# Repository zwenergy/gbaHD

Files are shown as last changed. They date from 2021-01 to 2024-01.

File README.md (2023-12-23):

# gbaHD
An open-source GBA consolizer.

To create a stable video signal without buffering whole frames, but rather
go line-by-line, the quartz crystal of the GBA is removed. Instead, 
the FPGA generates the clock signal for the GBA.

## Note
The latest bitstream (v1.4A) only works in conjunction with a Mancloud
shield. I will update the Arduino FW in the upcoming days, so the latest 
bitstream can be used with all gbaHD.

## Wiring
You need some basic soldering skills to wire all signals of the GBA to the
FPGA board and the controller to the Arduino. All responsibility is on
you. **I do not take any responsibility for any potential damages.** The 
following wiring works well for me. **Yet again, all risk is up to you.
If you want a more out-of-the-box experience, I strongly suggest you to
do not tinker around with your devices.** This is a simply hobby project of 
mine without a lot of testing.

In general, the test points of the GBA motherboard are not made for a
lot of soldering, so try to keep your soldering quick.

### SEA pins
The following figure shows an overview of the pins used for signals on
the Spartan Edge Accelerator board and the pin names used.

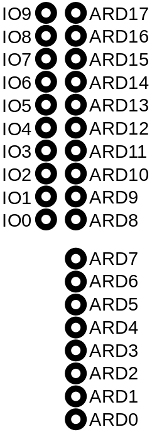
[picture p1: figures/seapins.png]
SEA pins


### Video signals
The following figure shows the test points for the display signals on
the GBA motherboard. I only used a 32 pin model so far, but the 40 pin
should have a similar layout. The test points can be found on the
frontside of the GBA motherboard close to the top.

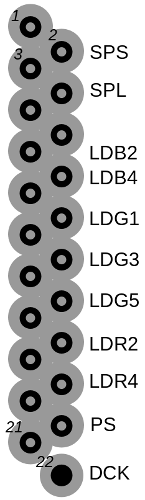
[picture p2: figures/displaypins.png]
SEA pins Display pins


The connections between the GBA display signals and the FPGA board are 
as follows (check the previous figures for the pin names). The "GBA Testpoint" 
column notes the testpoint to be connected to the corresponding FPGA
pin. The next columns (GBA LCD XX-pin) give additional information where
this signal is placed on the display ribbon cable.

| **FPGA Pin** | **GBA Testpoint** | GBA LCD 40-pin | GBA LCD 32-Pin | GBA SP 34-Pin |
|-|-|-|-|-|
| IO0 | 2 | 26 | 25 | 25 |
| IO1 | 5 | 23 | 22 | 22 |
| ARD5 | 6 | 22 | 21 | 21 |
| IO2 | 7 | 21 | 20 | 20 |
| ARD6 | 8 | 20 | 19 | 19 |
| IO3 | 9 | 19 | 18 | 18 |
| ARD7 | 10 | 17 | 16 | 16 |
| IO4 | 11 | 16 | 15 | 15 |
| ARD8 | 12 | 15 | 14 | 14 |
| IO5 | 13 | 14 | 13 | 13 |
| ARD9 | 14 | 13 | 12 | 12 |
| IO6 | 15 | 12 | 11 | 11 |
| ARD10 | 16 | 11 | 10 | 10 |
| IO7 | 17 | 10 | 9 | 9 |
| ARD11 | 18 | 9 | 8 | 8 |
| ARD13 | 19 | 8 | 7 | 7 |
| IO9 | 22 | 3 | 2 | 2 |

### Audio signals
The GBA generates a stereo 8 bit audio signals as a PWM which is then
amplified. We pick up both PWM signals using the following two
connections (the test point names can be found on the silkscreen of the
GBA motherboard).

| GBA Test Point  | FPGA Pin |
|---|---|
| S01 | ARD2 |
| S02 | ARD3 |

### Clock signal
The clock crystal has to be removed and a pad of the former crystal is 
connected to an FPGA pin. The following figure shows which pad has to be 
connected (the highlighted one) to the FPGA pin.

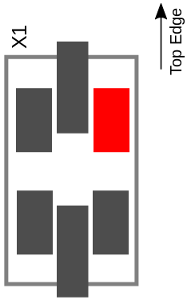
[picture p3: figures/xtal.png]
XTAL pin


| GBA | FPGA Pin |
|-----|---|
| XTAL pad  | IO8 |

### Controller signals
A cheap Arduino (e.g., a small Nano) handles the controller input (the 
FPGA board is not used here, as we would run out of pins here). The
following figure shows the pinout of a SNES controller plug.

SNES pinput SNES pinout

The SNES controller port is connected to the Arduino pins as follows:

| SNES controller | Arduino Pin |
|---|---|
| 5V | 5V |
| Clk | A1 |
| Latch | A0 |
| Data | A2 |
| Gnd | Gnd |

The following table shows the connections between the GBA motherboard
and Arduino pins for simulating the button presses.

|  GBA Test Point  | Arduino Pin |
|---|---|
| TP6 | D2 |
| TP7 | D3 |
| TP5 | D4 |
| TP4 | D5 |
| TP0 | D6 |
| TP1 | D7 |
| TP9 | D8 |
| TP8 | D9 |
| TP3 | D10 |
| TP2 | D11 |

### Arduino-FPGA connection
To activate or change the pixel grid, a connection between the Arduino
and the FPGA board is needed.

|  FPGA Pin  | Arduino Pin |
|---|---|
| ARD4 | A3 |

### Power connections
The GBA and Arduino can be powered via pins of the FPGA board. For the
GBA, the battery holders on the motherboard can be desoldered, as they are
not required anymore. Then connect the "B+" pad of the GBA motherboard to
the "3V3" pin of the SEA board and the GBA's "B-" pad to a GND pin of the
SEA board. Keep the power switch of the GBA on the ON position
(preferably fix it in this position, as the switch is quite smooth-running).

The Arduino requires 5V instead of 3.3V. For this, put the jumper 
"PWR_MODE" to the "ON" position. Then connect the 5V pin of the SEA
board's Arduino ICSP pins to the 5V pin of the Arduino.

## Custom Borders
Custom borders are currently in a kind of experimental state. Border images 
have to be in the dimensions of 320x180 pixels (going with the same resolution
of the Game Boy). Only the border is taken into account, the display area 
(middle 240x160) is ignored (see template.bmp). To generate a custom border, 
execute

`makeBorder.py <IMAGEFILE> (<CUTBITS>)`

The first parameter is the image file for the border, the second is an 
optional parameter for reducing the image color depth. After executing 
the script a new .vhdl should have been created. Replace the original 
`borderGen.vhdl` with this one and run the synthesis.

If the synthesis fails, the border is too complex. Try to simplify the 
border image or use the color depth reduction of the makeBorder.py script. 
The optional parameter sets the number of bits to reduce in color space. 
E.g., setting CUTBITS to 2 will reduce the color depth per color from 
8 bits to 6 bits.

## OSD, Smoothing and Pixel Grid
A 2x smoothing and 4x smoothing can be activated. These are slightly adapted
versions of the Scale2x algorithm. Note: Smoothing is currently disabled 
for 1080p resolution.

The pixel grid feature is currently also in an experimental state. Two
different pixel grids can be applied, a "bright" pixel grid (AGS feeling) 
or a "dark" pixel grid (AGB feeling).

To enter the OSD, press L+R+Select+Right. Smoothing and pixel grids can be activated there.

For the OSD, the connection between the 
FPGA board and the Arduino board (see previous sections) needs to be wired.

## FPGA Firmware
You can find the latest bitstream under the folder *bitstream*.

## TODOs

*README TODO:*
- Describe the overall project.
- Describe the different modules.
- Describe pinouts.
- Describe GBA video timing.

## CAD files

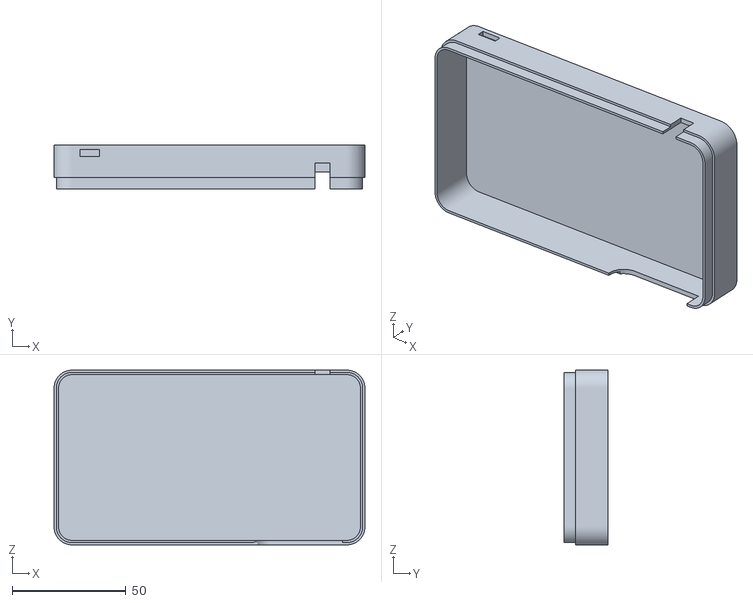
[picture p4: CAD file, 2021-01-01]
case/gbacasebottom.stl
137.0 x 19.3 x 77.0

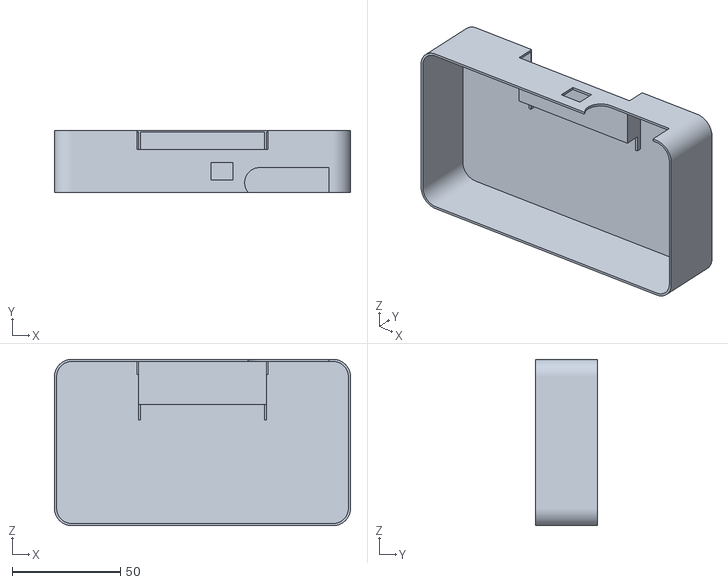
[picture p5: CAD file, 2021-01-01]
case/gbacase.stl
137.0 x 28.6 x 77.0

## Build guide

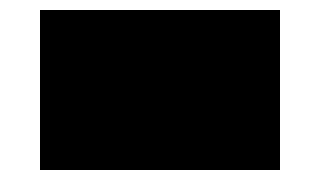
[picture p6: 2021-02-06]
scripts/makeBorder/template.bmp

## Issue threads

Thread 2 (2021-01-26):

Latest build reports 695p signal on some devices

codemasterv, 2021-01-26:
Some devices like my Sony TV, Samsung TV and Elgato HD 60 Pro report a 695p signal and refuse to display.

Other devices such as my Toshiba TV and  report the signal as 720p and works fine

On the previous build it worked on everything but the Samsung

Edit: Fixed in 01/27 update.

zwenergy, 2021-01-26:
I tried to fix it in the current commit. Is it working for you again?

codemasterv, 2021-01-27:
yep just popped in to makrk as resolved. Thanks for the update!

Closed 2021-01-27.

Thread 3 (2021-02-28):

Request / question

PrimoAngelo, 2021-02-28:
Great job! Do you think it is possible to add the pinout for the gamecube controller and the corresponding code for the arduino nano? For those like me who don't have Snes controllers and only have gamecube controllers and GC extension cables to sacrifice. Thanks so much for the work!

Liriel-666, 2021-05-08:
To what I knew use the gc only 1 data line and not 3 (data, clock, latch) .
He works not like a nes or snes pad.
That would need a full other firmware in the arduino.

And to be true gc gamepad are not really good for gba games

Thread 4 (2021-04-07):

The first column of pixels is too wide.

ChristopherHale, 2021-04-07:
The first column of pixels appears to be drawn 1.5 to 2 times the normal width of a pixel and the last column of pixels appears to be partially cut off or thinner. I've attached a photo from the Advance Wars editor screen, notice the left edge of the mountains when they're against the edge of the screen compared to when they're away from the edge of the screen.

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

ChristopherHale, 2021-04-26:
I’m looking into another issue right now but I noticed this extra wide column is misaligning the pixels to the pixel grid effect.

ChristopherHale, 2021-04-26:
![Uploading image.jpg…]()

ChristopherHale, 2021-04-27:
After counting the pixels the first pixel of each line is 9 pixels wide instead of the 6 pixels thereafter. The last pixel in the row is now 3 pixels wide and the pixel grid effect is chopping the pixels down the middle instead of being drawn between the pixels.

ChristopherHale, 2021-05-08:
Here are some more examples with the pixel grid turned on and I'm using a different display. The pixel grid does appear to be positioned correctly with the pixels being shifted partially to the right underneath it. Take note of the lettering and the orange pixels on the mountains. I tried looking through the FPGA code but I didn't see anything that jumps out at me but I'm guessing
 it happens sometime before the pixel grid effect is applied.

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

bkoropoff, 2022-01-30:
@zwenergy this bug should be fixed by #11

ChristopherHale, 2022-01-30:
Awesome! Thanks!

Closed 2022-01-31.

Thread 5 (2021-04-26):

Infrequent Restarts When Using 8bitdo Receiver

ChristopherHale, 2021-04-26:
When using the 8bitdo 2.4G SNES Receiver I’m experiencing infrequent restarts of the GBA and FPGA board. All the LEDs turn off and on again.

This seems to occur after leaving the console running and I’ve witnessed it happening after the first input into the wireless controller. There will then be several restarts in a row.

I haven’t seen this issue with a stock SNES or SFC controller. I’m going to see if I have a similar issue with my Bluetooth controller/receiver combo.

ChristopherHale, 2021-04-26:
I can confirm that the 8bitdo Bluetooth receiver is also causing tiny gbaHD to power cycle and restart. It happens without any interaction with the controller but does take about 5 minutes to occur.

bkoropoff, 2022-01-29:
@ChristopherHale the extra current drawn by a wireless receiver might be exceeding what your power supply can provide.  You could try putting a bypass capacitor across 5v and GND on the SNES controller connector, which will help if the excess current draw is a short transient.

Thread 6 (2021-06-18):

HDMI input recognized as TV input, but black screen

RianBeck, 2021-06-18:
The latest build as available on the google drive of Mogi_codemasterv works on my external computer monitor, however, I get a black screen in my panasonic viera tv (2014 model). I have tried older builds as well, but those don't even get recognized by the tv at all. On the latest build the tv does recognize the aspect ratio (16:9).

Would be very much appreciated if this could be fixed, as I would love to play on my tv, thanks!

Bertuga, 2021-06-24:
This is an issue with the TV. The gbaHD frequency is the same as the GBA which is not 60fps (it is something close to 59.72), a lot of TVs won't accept an irregular frame rate as this one. I'm also an viera owner (older model than yours) and it doesn't work as well, but it is the price to have it working as close as possible as the original hardware.

The GBA consolizer actually works at a 60fps, but the collateral effect of this is that everything runs slightly faster. Maybe it would be possible to implement this "60fps" mode to the gbaHD project, since the consolizer runs in an older fpga thant the gbaHD, to work as a compatibility mode for all TVs (the gba consolizer has two separate firmwares, to run at the original fps or the 60fps). I'm leaving this just as an suggestion, the project is amazing and I couldn't possibly ask for more.

RianBeck, 2021-06-24:
Thanks a lot for the explanation! Makes a lot more sense now. Indeed a 60Hz option would definitely be a nice to have, but as you say, amazing project, and I love it either way!

RianBeck, 2021-10-17:
The latest update has made the gbaHD compatible with my tv, thanks a lot for the great work!

Closed 2021-10-17.

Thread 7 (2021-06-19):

Incorrect vertical alignment

kyokohunter, 2021-06-19:
In my build the GBA video isn't vertically centered correctly. Resetting the ESP32 on the Spartan board changes the vertical alignment to a random position.

I thought this may be a quirk of my setup, as I'm building this around a GameBoy Player. The CPU is held in reset by the Arduino until ready (e.g waiting untile controller connected). I've wired the CPU directly and ruled that out as a cause, as exactly the same issue happens. I also checked my SPS (VSync) wiring with a multimeter and logic analyser and all seems fine there.

I only have one TV to test this on (Philips) and have tried the different HDMI inputs, as well as a couple of different HDMI cables.

I'm using the bitstream from this project as of 2nd June.

kyokohunter, 2021-06-26:
After investigating further it seems most of the time the picture is clipped off the top edge of the screen by about 160 lines.

I've decided to try learning FPGA development to help with this project but please bear with me whilst I learn the ropes (my background is front-end web dev and SQL!).

Increasing gbavideoystart in imageGen.vhd moves the GBA output but it ends up being clipped at the bottom, with the last 160 lines on the screen being blank.

I experimented with changing the countY position that a new frame in causes a jump to (changed to ystart); this causes jitter and lines repeating after the GBA video area.

I also experimented with changing vsync to occur after the active video area instead of before; this didn't make a change but it also didn't break the code.

Finally I experimented with a larger value for vbackporch; however I forgot to change maxVer before finishing work for the moment so I can't say if this would work or not! I'll report back when I can.

kyokohunter, 2021-06-27:
Changing the vfrontporch and vsync constants in imageGen.vhd hasn't made a difference either. I should also say that the TV is reporting 1280x720 at 60Hz correctly for the input and not some other resolution.

kyokohunter, 2021-07-01:
I've tried a different HDMI example and I also get the same problem (doesn't vsync) with that code, so there may be an issue with my SEA board or cables rather than the gbaHD code. I'll close this issue and try another board and cable that I've got on on order.

Closed 2021-07-01.

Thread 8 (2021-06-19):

No sound

kyokohunter, 2021-06-19:
I'm not getting any audio output via my TV. Whilst I'm planning to add a Bluetooth transmitter instead, I've spotted other people mentioning this on Reddit so I thought I would post the issue here.

As with the other issue I raised I only have one TV to test this on (Philips) and have tried the different HDMI inputs, as well as a couple of different HDMI cables and I'm using the bitstream from this project as of 2nd June.

It might be of interest this topic on the MiSTer FPGA forum about audio output issues with the GBA core:
https://misterfpga.org/viewtopic.php?f=20&t=55

neophoriac, 2021-06-19:
The audio issue, to my knowledge, is due to the fact that gbaHD outputs to DVI which originally doesn't carry audio. This means that even if the gbaHD outputs audio some TVs won't recognize it anyway as they don't expect audio. I have the same issue with my LG CX but if I connect it to an Asus monitor I can actually hear audio.

I would urge you to try the gbaHD to a different monitor(s) and see if the issue persist.

bkoropoff, 2022-02-13:
@zwenergy this might be fixed as of 1.3G

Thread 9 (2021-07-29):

Color Issues? (Also odd game issues)

TheIcedTeaAddict, 2021-07-29:
Hello, I must say that I've absolutely loved playing my Gameboy games on the TV with an SNES controller.
But I've ran into two issues so far, one that has been consistent for some reason despite trying wiring everything again. The other is one that I just recently found. So I hope to get some help trying to fix these issues.

The first issue is fairly major, as it is a very strange color issue, which will be included in these photos.
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
I have no idea why this issue has been consistent, but I've even searched up the service manual for the 40 pin motherboard that I have and found nothing that could be causing this. Which is unfortunate since I really wanted to fix this issue myself without making this into a topic.
The first time I tried to build this project, the same thing happened, but I was using the test pads. So I tried again and ended up burning off the gba pads, once I did this I ordered a ribbon cable PCB so I could use the LCD cable slot. which worked, but gave me the same results. So I took all the wires off the FPGA board and resoldered better/thicker wires onto them and another ribbon cable PCB, still same result, so right now I feel like I'm at a dead end. I hope to get some possible solutions that could help fix this issue.

Now here is another issue I ended up finding, I have reproduction copies of Metroid Fusion, Harvest Moon and a few other games, but only the first two have issues. Both Metroid Fusion and Harvest Moon hang after getting past the Game Boy Advance logo. No sound and only a blue tinted screen. (It would be a white screen, but the color issue above.) I assume because these two have the same board and both are missing a 1n4148 Diode, but I find it odd since these two work just fine on my SP. Either way, I don't care much if this issue fixed on the end of GBAHD as I could probably fix it by soldering a diode to the pads, I just found this issue interesting and strange to think about. lol. (If you are interested in looking into this for some reason, the boards are BX2006_TSOPGA_6108.)

TheIcedTeaAddict, 2021-07-30:
Just going to add that this a AGB-CPU-04 board with a CPU AGB A. Going to mention that in case that's important for this.

ManCloud, 2021-11-29:
Could you please share a picture of your soldering work on the Spartan side with us?
The solderpads on the SEA board are pretty bad to be soldered so bad joints here were the main cause for troubles like this in the past.

bkoropoff, 2022-02-04:
@TheIcedTeaAddict

Check that your HDMI cable is good and that the mini-HDMI connector on the Spartan board was properly soldered, hasn't been damaged, etc.  It seems like it might be possible to lose the HDMI TMDS channel carrying red and have a very tolerant display still manage to interpret the rest as a DVI signal.  You would not get any audio in this case.  A quick google search shows that people have complained about missing red with shoddy HDMI connectors.

philipguin, 2024-09-27:
For anyone googling this, I had an issue where my video output was all tinted green, turns out two pins were shorted (CPU top side, pins 2 and 3 from right, if looking at CPU upright). The pins between the CPU and RAM can also cause all kinds of visual issues if shorted or not connected.

The real solution is to get a voltage meter and a pair of micro-sized leads and test every single pin to rule issues out. (It’s a bit tedious but not that hard.) This removes all guesswork and makes problems of this nature purely a matter of persistence, no luck required.

Good luck!

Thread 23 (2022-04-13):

1080i or 1080p ?

MstrVLT, 2022-04-13:
https://github.com/zwenergy/gbaHD/blob/bdd5c99203d8f072479f976f6c7da6ff4cb5412b/hdl/definePackage.sv#L52

I use Elgato capture card hd60s plus, i known about many issues with use this card in non standart resolutions, frame rate, etc.
But few times I've seen in OBS green screen image and Elgato detect source frame rate 60.05 Hz. My old tv detect 1080i not 1080p
I dug into the code and found a little strange thing  localparam pxlClkFrq_60hz = 148500.0; // for RES0_1080P
But this paper https://www.uniforcesales.com/wp-content/uploads/2015/07/ITS-Transition-from-NTSC-Analog-to-HD-Digital.pdf   said me: for 1080i/30 (60Hz field rate) =(1125 x 2200/2) x 20 bits/pixel x 60 fields/sec = 24,750,000/field x 60 = 1,485,000,000 bits/sec
PS Thx for the awesome opportunity to use GBA on the big screen! I would like to help in the development of this project, but I am only at the beginning of the study of VHDL

MstrVLT, 2022-04-13:
In SNLA232
1920 X 1080/60/P = 2970000000
1920 X 1080/59.94/P = 2967030000

MstrVLT, 2022-04-13:
I saw - you are using 10 bit color. Sorry
I have no more ideas why detect 60.05 Hz (((

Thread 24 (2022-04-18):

480P pxlClkFrq_60hz wrong

MstrVLT, 2022-04-18:
in line: https://github.com/zwenergy/gbaHD/blob/bdd5c99203d8f072479f976f6c7da6ff4cb5412b/hdl/definePackage.sv#L12
may be use  27027.0 ?
like:
https://github.com/hdl-util/hdmi/blob/b2e5688bf02b75d525918026e7032d36c540c10f/src/hdmi.sv#L204

zwenergy, 2022-04-19:
For 480p, the 59.94 Hz refresh rate mode is used since it's nicer to deriver a suitable clock for this. This is the reason for the 27 MHz pixel clock.

Closed 2022-04-20.

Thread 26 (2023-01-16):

How to select 480p output?

unmaker64, 2023-01-16:
Sorry for the noob question but I can't figure out how to set the output to 480p. The only options I see are 720p and 1080p. Thanks

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

zwenergy, 2023-02-08:
480p is not included by the ManCloud shield by default, as the ESP32 only has enough memory to store 2 bitstreams at the same time. You can download the 480p bitstream from this repo, rename it to either replace the 720p bitstream or 1080p bitstream and place it onto the SD card. Here's more information on that
https://github.com/gbaHD/GBAHD-Shield/wiki/nicetoknowmisc

Closed 2023-04-03.

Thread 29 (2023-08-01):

Defaults

Krystman, 2023-08-01:
Is there a way to set up default settings for the device? I would love my GBA HD to use 59.7 Hz by default

zwenergy, 2023-08-07:
Saving settings is currently not supported but being worked on. Though, if you synthesize the gbaHD FPGA firmware by yourself, you can change the default settings. In this [line ](https://github.com/zwenergy/gbaHD/blob/a0d69205433213d248c215f12e01b34674017702/hdl/osd.vhd#L364), change to the following to set the 59.7 Hz mode as the default
`framerate <= '1';`

Closed 2023-08-07.

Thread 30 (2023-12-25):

1.4A OSD not working

unmaker64, 2023-12-25:
Hi I've just updated the firmware to the latest 1.4A via the OTA. Now I'm unable to access the OSD. I'm using the Mancloud shield

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

DorDur215, 2023-12-26:
I am having the same issue.

I've updated to 1.4A and when I try to open the OSD it doesn't open and my buttons stop responding until I press START again.

I am also using ManCloud's Shield.

unmaker64, 2023-12-27:
It works now after updating the ESP Application. Thank you very much for your hard work

Closed 2023-12-27.

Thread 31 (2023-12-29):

gbaHD is randomly resetting on its own

unmaker64, 2023-12-29:
Hi there,

I've been experiencing random resets and I can't figure out what the issue could be. And by reset I mean the console is power cycling. It's been happening anywhere between just a few minutes to a few hours of playing, most often between 30 to 90 minutes of playing. They happen both in 1080p and 720p modes at 60Hz. I've tried multiple power supplies, both 5V 1A and 5V 2A. I've had resets while using an OEM SNES controller, 8BitDo 2.4GHz SNES controller, and a few different bluetooth controllers. What controller I use doesn't seem to make a difference. My gbaHD is built using an AGB-CPU-02 with the capacitors replaced and the Mancloud shield with an ATMEGA168p.

Out of curiosity, I let my console run for 24 hours and it didn't reset during that time. It only seems to reset randomly when it's receiving inputs from a controller.

I'm really stumped here. Could the ATMEGA168p be the issue? I'm using the 168p because the ATMEGA328p was out of stock at both Digikey and Mouser at the time I ordered my parts.

On a side note, I've noticed the WebUI is very stable now with the latest firmware. With previous firmwares it would randomly timeout after roughly 5 to 20 minutes, so thank you very much for that.

unmaker64, 2024-01-07:
Well I spoke too soon. My console is power cycling without any controller inputs.

zwenergy, 2024-01-22:
Did you have this issue also before updating?

unmaker64, 2024-01-22:
Thanks for the reply.

I didn't notice this issue with firmware 1.3H, which is the firmware that I've played on the most. I only very briefly played on firmwares 1.3I and 1.3J, so I'm unsure if I would have had the issue with those. It wasn't until firmware 1.4A that I started to play more GBA again and noticed the issue. I have two fully assembled consoles with me and I have the same issue with both.

I should mention that I have sold a few of these and the initial console I had played on a lot was sold a while ago. I'm trying to remember any differences in the way I may have assembled them. The only notable thing that comes to mind is the way I programmed the SEA boards. The consoles I have now with the reset issue were programmed using the CMD-Shell method as described in the Shield wiki. I used this method as I was having too much trouble getting the installation to complete when using the https://gbahd.github.io/ link. I'll try to reprogram them using the https://gbahd.github.io/ link and see if that makes a difference.

unmaker64, 2024-01-22:
As I remember, I'm having issues getting the installation to complete when using the https://gbahd.github.io/ link. I'm able to get the installation to initialize by holding the BOOT button while clicking on Install but it eventually fails to complete. I may have just found a workaround for that which is not to just hold the BOOT button while clicking Install, but by holding the BOOT button until the installation completes. I also selected the Erase option. I'll let my console run now and see if there's any improvement.

unmaker64, 2024-01-22:
Unfortunately that didn't seem to help. My console reset about 1 hour in

unmaker64, 2024-02-02:
I was able to run both consoles for 50 hours without a reboot using the new 1.6.1 firmware. Thank you guys very much for the workaround

unmaker64, 2024-03-15:
Unfortunately I'm still getting occasional resets with shield version 1.6.1 so I've decided to reopen the issue.

If I understand correctly, the random resets are caused by some sort of bug while the WebUI is active. I believe the current firmware is meant to be a workaround for this issue by forcing the WebUI to become inactive after 3 to 5 minutes. What I've noticed is the WebUI does not consistently shut down after 3 to 5 minutes. Sometimes it will shut down after 3 minutes, sometimes after 10 minutes, and sometimes it's still active 50 minutes later. I've had a few resets occur because the WebUI did not shut down after the 3 to 5 minutes as I believe it should.

I was wondering if this is a known issue or if maybe something funky is going on with my setup. Any help would be greatly appreciated.

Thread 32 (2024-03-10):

Feature Request: Built in Borders

AdeCarter, 2024-03-10:
Hello,

Is it possible to have some borders built in and selectable via the OSD? I'm aware that you can add custom ones but its a little beyond me. Having 2/3 selectable via the OSD would be lovely.

Perhaps a DMG and a GBC one along side a partial GBA housing one perhaps?

Appreciate this is a feature request not a bug, also happy to pay a bounty to get this added if need be.

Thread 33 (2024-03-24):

Is it possible to completely disable the WebUI

unmaker64, 2024-03-24:
Hello,

Currently with 1.6.1 firmware random resets are far less common but it seems there's still a roughly 1 to 3% chance that a reset will occur within the first 15 minutes of the console being powered on. Although the odds are low, I would prefer that there's a 0% chance of a reset occurring. As I understand it, a bug with the WebUI is to blame for the resets. So I was wondering if it's possible, through firmware or with the addition of a new setting, to disable the WebUI for the time being until the reset bug is fully resolved.

Many thanks

zwenergy, 2024-03-29:
Yes, that should be possible. Yet, this repository is actually for the FPGA FW only, the WebUI FW is part of the gbaHD shield over here:
https://github.com/gbaHD/GBAHD-Shield

Please open the issue over there :) .

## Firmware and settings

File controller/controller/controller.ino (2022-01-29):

// Which controller convention to use.
//
// 'SNES' uses B and Y as the primary and secondary buttons
// (GBA A and B), which matches what most SNES games use
// and how your thumb is intended to rest on the face
// buttons.
//
// 'LITERAL' maps SNES A and B to GBA A and B.
//#define CONVENTION SNES
#define CONVENTION LITERAL

// Pin definitions.
// GBA outputs.
// These definitions are just for reference. If other pins should be used,
// the updateGBASignals function needs to be adjusted.
#define DUP 2
#define DDOWN 3
#define DLEFT 4
#define DRIGHT 5
#define BUTA 6
#define BUTB 7
#define BUTL 8
#define BUTR 9
#define BUTSTART 10
#define BUTSELECT 11

// SNES controller.
#define SNESLATCH A0
#define SNESCLK A1
#define SNESSERIAL A2

// Communication port
#define COMPIN A3

// Polling interval in ms.
#define POLLINT 10

// Some NOP definitions.
// Yes, this is very pretty. But we do not have code size problems,
// hence using stupid sequences of NOPs makes it nicely timing 
// predictable.
#define NOP1 asm volatile( "nop\n" )
#define NOP5 NOP1; NOP1; NOP1; NOP1; NOP1
#define NOP10 NOP5; NOP5
#define NOP20 NOP10; NOP10
#define NOP40 NOP20; NOP20
#define NOP80 NOP40; NOP40

#define WAIT2US NOP20; NOP10; NOP1
#define WAIT8US NOP80; NOP40; NOP5; NOP1; NOP1; NOP1

// Conventions
#define SNES 0
#define LITERAL 1

// The latest controller state.
uint8_t conA;
uint8_t conB;
uint8_t conDUp;
uint8_t conDDown;
uint8_t conDLeft;
uint8_t conDRight;
uint8_t conL;
uint8_t conR;
uint8_t conStart;
uint8_t conSelect;

uint8_t gotCombo;


// Read the controller.
void readController() {
  // Set the latch to high for 12 us.
  digitalWrite( SNESLATCH, 1 );
  delayMicroseconds( 12 );
  digitalWrite( SNESLATCH, 0 );
  delayMicroseconds( 6 );

  // Init A and B.
  conB = 0;
  conA = 0;

  // Shift in the controller data.
  for ( uint8_t i = 0; i < 16; ++i ) {
    digitalWrite( SNESCLK, 0 );
    delayMicroseconds( 6 );
    // We only care about the first 12 bits.
    if ( i < 12 ) {
      uint8_t curDat = !digitalRead( SNESSERIAL );
      switch ( i ) {
        case 0:
#if CONVENTION == SNES
          conA |= curDat;
#else
          conB |= curDat;
#endif
          break;
        case 1:
          conB |= curDat;
          break;
        case 2:
          conSelect = curDat;
          break;
        case 3:
          conStart = curDat;
          break;
        case 4:
          conDUp = curDat;
          break;
        case 5:
          conDDown = curDat;
          break;
        case 6:
          conDLeft = curDat;
          break;
        case 7:
          conDRight = curDat;
          break;
        case 8:
          conA |= curDat;
          break;
        case 9:
#if CONVENTION == SNES
          conB |= curDat;
#else
          conA |= curDat;
#endif
          break;
        case 10:
          conL = curDat;
          break;
        case 11:
          conR = curDat;
          break;
        default:
          break;
        
      }
    }
    digitalWrite( SNESCLK, 1 );
    delayMicroseconds( 6 );
  }
}


// Drive GBA controller signals.
void updateGBASignals() {
  // In case a button is pressed, we pull the signal to ground.
  // Otherwise, we set it to high Z.
  // Since all output registers are already set to 0, we only need
  // to toggle the port direction.
  // Get D0 and D1 directions.
  uint8_t d1d0 = DDRD;
  d1d0 = d1d0 & 0b00000011;
  uint8_t dir = d1d0 | ( conDUp << 2 ) | ( conDDown << 3 ) | ( conDLeft << 4 ) |
    ( conDRight << 5 ) | ( conA << 6 ) | ( conB << 7 );
  // Write them.
  DDRD = dir;

  // The next ones.
  dir = ( conL ) | ( conR << 1 ) | ( conStart << 2 ) | ( conSelect << 3 );
  DDRB = dir; 
}

void setup() {
  // DEBUG.
  Serial.begin(9600);
  Serial.println( "Startup" );
  
  // Set up pin modes.
  // First set all output registers of GBA buttons to 0.
  pinMode( DUP, OUTPUT );
  digitalWrite( DUP, 0 );
  pinMode( DDOWN, OUTPUT );
  digitalWrite( DDOWN, 0 );
  pinMode( DLEFT, OUTPUT );
  digitalWrite( DLEFT, 0 );
  pinMode( DRIGHT, OUTPUT );
  digitalWrite( DRIGHT, 0 );
  pinMode( BUTA, OUTPUT );
  digitalWrite( BUTA, 0 );
  pinMode( BUTB, OUTPUT );
  digitalWrite( BUTB, 0 );
  pinMode( BUTL, OUTPUT );
  digitalWrite( BUTL, 0 );
  pinMode( BUTR, OUTPUT );
  digitalWrite( BUTR, 0 );
  pinMode( BUTSTART, OUTPUT );
  digitalWrite( BUTSTART, 0 );
  pinMode( BUTSELECT, OUTPUT );
  digitalWrite( BUTSELECT, 0 );

  // Then GBA pins are set to input to hold
  // them as high Z.
  pinMode( DUP, INPUT );
  pinMode( DLEFT, INPUT );
  pinMode( DRIGHT, INPUT );
  pinMode( DDOWN, INPUT );
  pinMode( BUTA, INPUT );
  pinMode( BUTB, INPUT );
  pinMode( BUTL, INPUT );
  pinMode( BUTR, INPUT );
  pinMode( BUTSTART, INPUT );
  pinMode( BUTSELECT, INPUT );

  // And the SNES controller pins.
  pinMode( SNESLATCH, OUTPUT );
  digitalWrite( SNESLATCH, 0 );
  pinMode( SNESCLK, OUTPUT );
  digitalWrite( SNESCLK, 1 );
  pinMode( SNESSERIAL, INPUT_PULLUP );

  // Communication pin.
  pinMode( COMPIN, OUTPUT );
  digitalWrite( COMPIN, 1 );

}

void sendPacket( uint8_t p ) {
  uint8_t curPort = PINC;
  for ( uint8_t i = 0; i < 8; ++i ) {
    uint8_t curBit = p & ( 1 << i );
    if ( curBit ) {
      curPort &= B11110111;
      PORTC = curPort;
      WAIT2US;
      curPort |= B00001000;
      PORTC = curPort;
      WAIT8US;
    } else {
      curPort &= B11110111;
      PORTC = curPort;
      WAIT8US;
      curPort |= B00001000;
      PORTC = curPort;
      WAIT2US;
    }
  }
}

void noButtons() {
  conA = 0;
  conB = 0;
  conDUp = 0;
  conDDown = 0;
  conDLeft = 0;
  conDRight = 0;
  conR = 0;
  conL = 0;
  conStart = 0;
  conSelect = 0;
}

uint8_t showOSD = 0;

void loop() {
  readController();

  // Button combination L+R+SELECT+RIGHT send a communcation pulse.
  if ( conSelect && conL && conR && conDRight ) {
    if ( gotCombo == 0 ) {
      showOSD = !showOSD;
      gotCombo = 1;

      // Set the buttons to off once.
      noButtons();
      updateGBASignals();
    }
  } else if ( gotCombo == 1 ) {
    gotCombo = 0;
  }

  // Only update GBA signals if the menu is not active.
  if ( !showOSD ) {
    updateGBASignals();  
  }

  // Prepare packet to send.
  uint8_t packet = ( conB << 7 ) | ( conA << 6 ) | ( conDLeft << 5 ) | ( conDRight << 4 ) | ( conDDown << 3 ) | ( conDUp << 2 ) | ( showOSD << 1 );
  sendPacket( packet );

  delay( POLLINT );

}

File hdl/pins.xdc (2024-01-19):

set_property CFGBVS VCCO [current_design]
set_property CONFIG_VOLTAGE 3.3 [current_design]

#set_property IOSTANDARD LVCMOS33 [get_ports {key[0]}]
#set_property IOSTANDARD LVCMOS33 [get_ports led]
set_property IOSTANDARD LVCMOS33 [get_ports clk]
#set_property PACKAGE_PIN J1 [get_ports led]
set_property PACKAGE_PIN H4 [get_ports clk]
#set_property PACKAGE_PIN C3 [get_ports {key[0]}]

# FPGA IO0
set_property PACKAGE_PIN N14 [get_ports vsync]
# FPGA IO1
set_property PACKAGE_PIN M14 [get_ports {bluePxl[0]}]
# FPGA IO2
set_property PACKAGE_PIN C4 [get_ports {bluePxl[2]}]
# FPGA IO3
set_property PACKAGE_PIN B13 [get_ports {bluePxl[4]}]
# FPGA IO4
set_property PACKAGE_PIN N10 [get_ports {greenPxl[1]}]


# FPGA IO5
set_property PACKAGE_PIN M10 [get_ports {greenPxl[3]}]
# FPGA IO6
set_property PACKAGE_PIN B14 [get_ports {redPxl[0]}]
# FPGA IO7
set_property PACKAGE_PIN D3 [get_ports {redPxl[2]}]
# FPGA IO8
set_property PACKAGE_PIN P5 [get_ports gbaClk]
# FPGA IO9
set_property PACKAGE_PIN E11 [get_ports dclk]

# FPGA AR D4
set_property PACKAGE_PIN A5 [get_ports controllerMCUIn]
set_property IOSTANDARD LVCMOS33 [get_ports controllerMCUIn]

# FPGA AR D5
set_property PACKAGE_PIN B5 [get_ports {bluePxl[1]}]
# FPGA AR D6
set_property PACKAGE_PIN A4 [get_ports {bluePxl[3]}]
# FPGA AR D7
set_property PACKAGE_PIN A3 [get_ports {greenPxl[0]}]
# FPGA AR D8
set_property PACKAGE_PIN B3 [get_ports {greenPxl[2]}]
# FPGA AR D9
set_property PACKAGE_PIN A2 [get_ports {greenPxl[4]}]
# FPGA AR D10
set_property PACKAGE_PIN B2 [get_ports {redPxl[1]}]
# FPGA AR D11
set_property PACKAGE_PIN B1 [get_ports {redPxl[3]}]
# FPGA AR D13
set_property PACKAGE_PIN H2 [get_ports {redPxl[4]}]

# Audio Pins.
# Audio Right (FPGA_AR_D2)
set_property PACKAGE_PIN A10 [get_ports audioRIn]
set_property IOSTANDARD LVCMOS33 [get_ports audioRIn]
# Audio Left (FPGA_AR_D3)
set_property PACKAGE_PIN B6 [get_ports audioLIn]
set_property IOSTANDARD LVCMOS33 [get_ports audioLIn]

# AR_3v3_EN
set_property PACKAGE_PIN L13 [get_ports enable3V3]
set_property IOSTANDARD LVCMOS33 [get_ports enable3V3]


# ADC Pins.
# D7
#set_property PACKAGE_PIN H12 [get_ports {adcDatIn[7]}]
# D6
#set_property PACKAGE_PIN H11 [get_ports {adcDatIn[6]}]
# D5
#set_property PACKAGE_PIN C11 [get_ports {adcDatIn[5]}]
# D4
#set_property PACKAGE_PIN F12 [get_ports {adcDatIn[4]}]
# D3
#set_property PACKAGE_PIN E12 [get_ports {adcDatIn[3]}]
# D2
#set_property PACKAGE_PIN D12 [get_ports {adcDatIn[2]}]
# D1
#set_property PACKAGE_PIN J2 [get_ports {adcDatIn[1]}]
# D0
#set_property PACKAGE_PIN J3 [get_ports {adcDatIn[0]}]
# ADC Clk
#set_property PACKAGE_PIN C5 [get_ports adcClkOut]
# ADC nOE
#set_property PACKAGE_PIN J4 [get_ports adcnOE]

#set_property IOSTANDARD LVCMOS33 [get_ports adcDatIn]
#set_property IOSTANDARD LVCMOS33 [get_ports adcClkOut]
#set_property IOSTANDARD LVCMOS33 [get_ports adcnOE]

# GBA pins.

set_property IOSTANDARD LVCMOS33 [get_ports {redPxl[4]}]
set_property IOSTANDARD LVCMOS33 [get_ports {redPxl[3]}]
set_property IOSTANDARD LVCMOS33 [get_ports {redPxl[2]}]
set_property IOSTANDARD LVCMOS33 [get_ports {redPxl[1]}]
set_property IOSTANDARD LVCMOS33 [get_ports {redPxl[0]}]
set_property IOSTANDARD LVCMOS33 [get_ports {greenPxl[4]}]
set_property IOSTANDARD LVCMOS33 [get_ports {greenPxl[3]}]
set_property IOSTANDARD LVCMOS33 [get_ports {greenPxl[2]}]
set_property IOSTANDARD LVCMOS33 [get_ports {greenPxl[1]}]
set_property IOSTANDARD LVCMOS33 [get_ports {greenPxl[0]}]
set_property IOSTANDARD LVCMOS33 [get_ports {bluePxl[4]}]
set_property IOSTANDARD LVCMOS33 [get_ports {bluePxl[3]}]
set_property IOSTANDARD LVCMOS33 [get_ports {bluePxl[2]}]
set_property IOSTANDARD LVCMOS33 [get_ports {bluePxl[1]}]
set_property IOSTANDARD LVCMOS33 [get_ports {bluePxl[0]}]
set_property IOSTANDARD LVCMOS33 [get_ports dclk]
set_property IOSTANDARD LVCMOS33 [get_ports vsync]
set_property IOSTANDARD LVCMOS33 [get_ports gbaClk]

# HDMI pins.

set_property IOSTANDARD TMDS_33 [get_ports {hdmiTX[0]}]
set_property IOSTANDARD TMDS_33 [get_ports {hdmiTXN[0]}]
set_property PACKAGE_PIN G1 [get_ports {hdmiTX[0]}]
set_property PACKAGE_PIN F1 [get_ports {hdmiTXN[0]}]
set_property IOSTANDARD TMDS_33 [get_ports {hdmiTX[1]}]
set_property IOSTANDARD TMDS_33 [get_ports {hdmiTXN[1]}]
set_property PACKAGE_PIN E2 [get_ports {hdmiTX[1]}]
set_property PACKAGE_PIN D2 [get_ports {hdmiTXN[1]}]
set_property IOSTANDARD TMDS_33 [get_ports {hdmiTX[2]}]
set_property IOSTANDARD TMDS_33 [get_ports {hdmiTXN[2]}]
set_property PACKAGE_PIN D1 [get_ports {hdmiTX[2]}]
set_property PACKAGE_PIN C1 [get_ports {hdmiTXN[2]}]
set_property IOSTANDARD TMDS_33 [get_ports hdmiClkN]
set_property IOSTANDARD TMDS_33 [get_ports hdmiClk]
set_property PACKAGE_PIN G4 [get_ports hdmiClk]
set_property PACKAGE_PIN F4 [get_ports hdmiClkN]
set_property IOSTANDARD LVCMOS33 [get_ports hdmiCEC]
set_property IOSTANDARD LVCMOS33 [get_ports hdmiSDA]
set_property IOSTANDARD LVCMOS33 [get_ports hdmiSCL]
set_property IOSTANDARD LVCMOS33 [get_ports hdmiHPD]
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

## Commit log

2020-10-04 Added TERC4 encoder and ECC module.
2020-12-21 Fix bug in controller program.
    [controller.ino]
2021-01-01 Added case.
    [gbacase.stl, gbacasebottom.stl]
2021-01-02 Started to add wiring infos.
2021-01-02 Fixed pin label in image.
2021-01-03 Fixed old xdc file and added some more wiring info.
    [pins.xdc]
2021-01-09 Fixed GBA display capture bug and added a bit more wiring info.
2021-01-19 Fix blue pixel pin.
    [pins.xdc]
2021-02-03 Update README.md
    Rename GBA Display Pin to GBA 40-Pin Testpoint, this should make it less confusing, add GBA SP LCD pinout
2021-02-13 Enabled sending AVI frames.
2021-02-14 Send audio info frame.
2021-05-09 Added smoothing filter.
2021-08-21 Replaced video out with external core.
    [pins.xdc]
2021-12-19 Framerate adjusting and bug fixes.
    * Added 60*/59.7Hz framerate to OSD.
    * Fixed audio channel swap.
    * Enable AR_3V3 line.
    [pins.xdc]
2022-01-11 pwm2pcm: remove unused logic
2022-01-12 pwm2pcm: fix off-by-one error
    The bit width of the PWM counters was 1 greater than needed,
    effectively attenuating output by an additional 1/2th.
2022-01-12 pwm2pcm: output signed samples
    HDMI requires signed audio samples. The current implementation
    gets away with unsigned samples because it attenuates the
    output enough to avoid ever setting MSB bit and causing distortion
    due to overflow.
    With this change, it's safe to operate with a damp parameter
    of 0.
2022-01-12 pwm2pcm: add first-order IIR low-pass filter
    This removes some high-frequency noise from the output
    which is audible with a low damp parameter or high gain
    in the audio path.
2022-01-29 controller: use SNES convention
    SNES games typically use B as the primary action (e.g. jump) and Y as
    the secondary action (e.g. fire). Map these to GBA A/B to preserve the
    convention players are accustomed to rather than literal button names.
    The literal convention can still be used by switching an ifdef.
2022-01-29 imagegen: sync hdmi output with GBA differently
    Using the new upstream START_X/START_Y parameters, the hdmi block
    is held in reset until the start of the first GBA frame.
2022-02-01 New pwm2pcm implementation
    This deals with the fact that the GBA sample rate is under software
    control and can vary within a large range. It also makes several
    other improvements.
    - PWM counter values are normalized so that sample rate changes
    don't change the effective volume.
    - Sample rate conversion uses a proper upsample/decimate
    pipeline.
    - The IIR filter uses extra precision for intermediate results
    to reduce noise.
2022-02-06 pwm2pcm: fix unconnected signal
    This has less effect on the output than you would think.
2022-10-01 Swapped audio channels, updated to v1.3I.
    [pins.xdc]
2024-01-19 Added new color correction.
    [pins.xdc]
